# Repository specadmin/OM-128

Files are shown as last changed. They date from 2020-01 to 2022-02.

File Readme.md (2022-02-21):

# ATmega1284p Development Board #

ATmega1284p provides maximum AVR capabilities in small QFN44 package only 7х7 mm size. This controller is much better than other Atmel AVR devices (ATmega128, ATmega328, ATmega32 etc).

## Board description ##

* Programm flash size: 128 кБ
* RAM size: 16 кБ
* EEPROM size: 4кБ
* CPU clock frequency: up to 20 MHz.
* Power supply voltage: 4...6 V
* Power supply polarity protection
* Power supply filter
* 24 I/O ports
* 6 LEDs (1 power + 5 configurable)
* Reset button
* Pads for ADC reference resistors
* SPI interface
* Dimensions: 36 х 20 х 4 mm

This repository contains
* OM-128 development board schematics;
* OM-128 PCB design in Gerber format;
* a default firmware for OM-128 development board.

## PCB ##

Front view
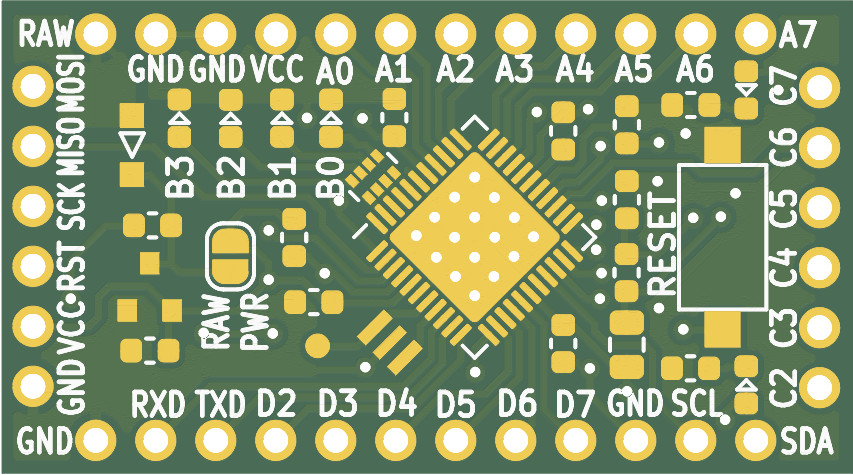
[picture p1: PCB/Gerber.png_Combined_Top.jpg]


Rear view
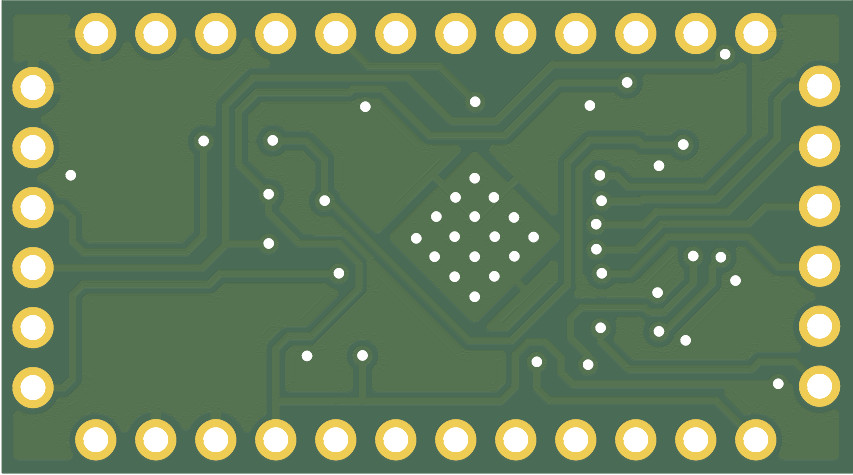
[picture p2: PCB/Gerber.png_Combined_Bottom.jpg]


## Available for purchasing ##

https://www.avito.ru/krasnodar/tovary_dlya_kompyutera/otladochnyy_modul_avr_atmega1284p_1904795755

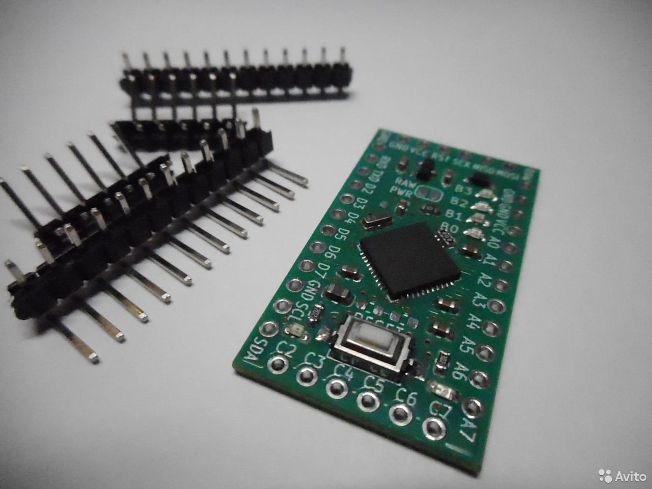
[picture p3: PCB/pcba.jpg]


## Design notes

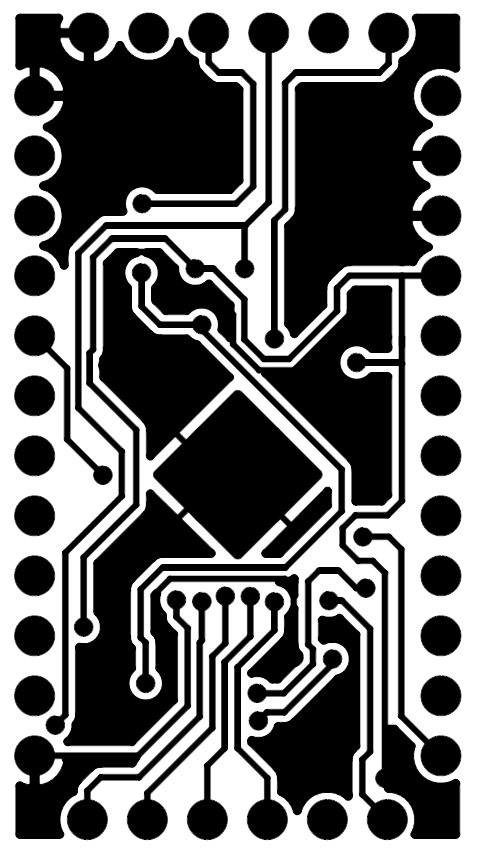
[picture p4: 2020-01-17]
PCB/Gerber_Layer_Copper_Bottom.png

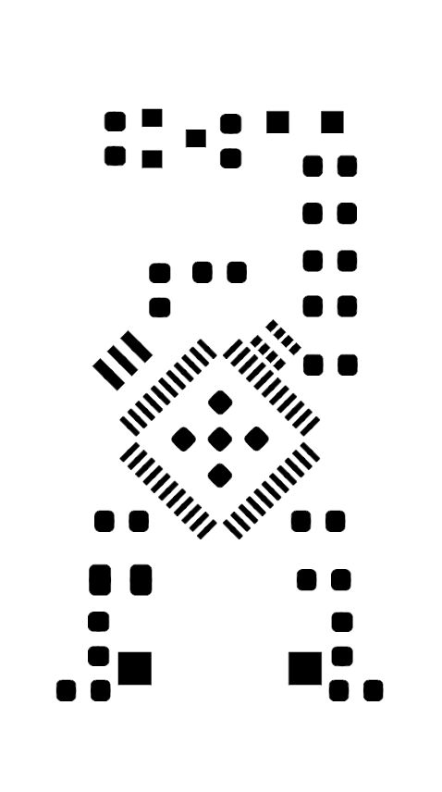
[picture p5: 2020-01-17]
PCB/Gerber_Layer_Paste_Top.png

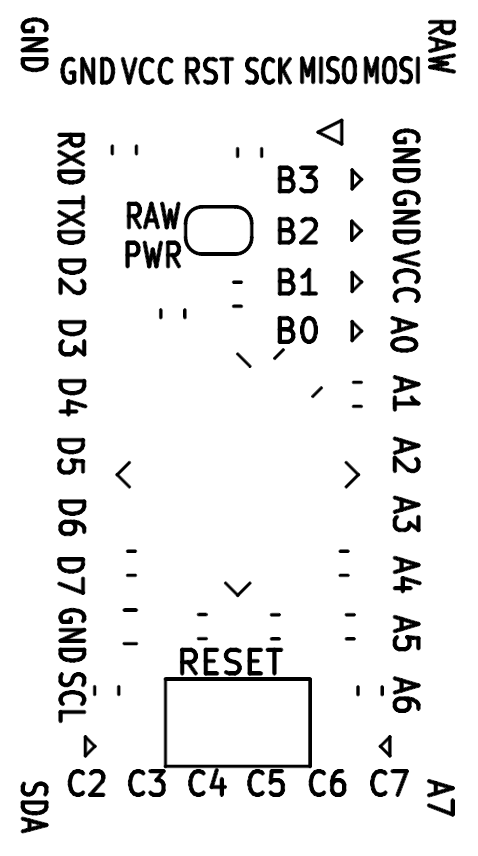
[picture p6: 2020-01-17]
PCB/Gerber_Layer_Silk_Top.png

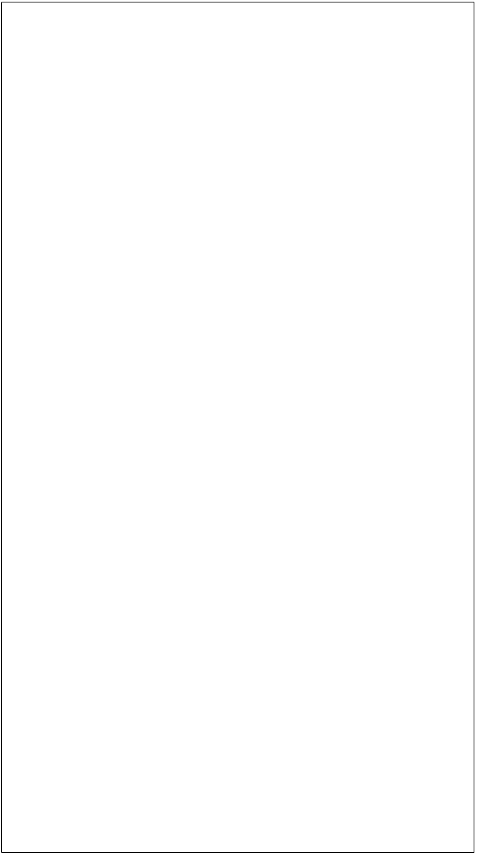
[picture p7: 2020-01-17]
PCB/Gerber_Layer_Outline_Both.png

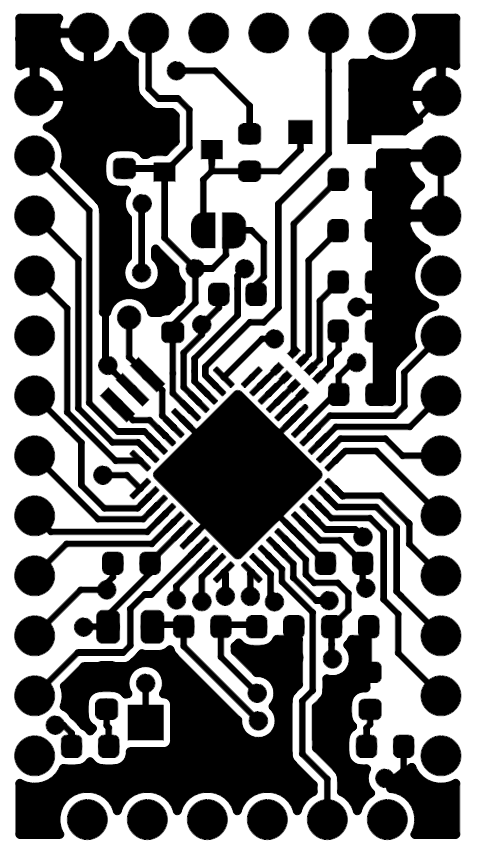
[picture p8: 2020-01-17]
PCB/Gerber_Layer_Copper_Top.png

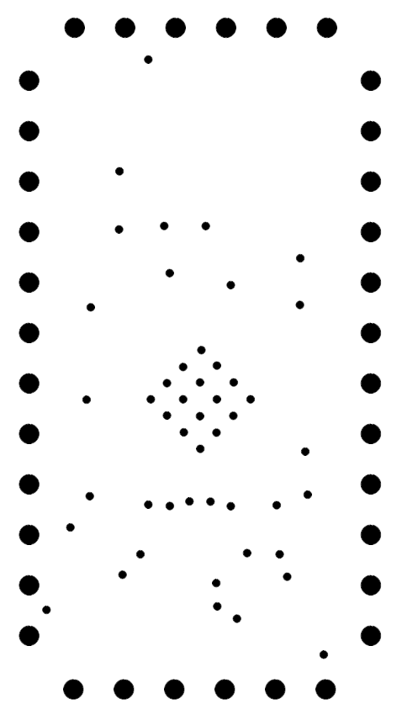
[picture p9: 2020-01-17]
PCB/Gerber_Layer_Drill_Both.png

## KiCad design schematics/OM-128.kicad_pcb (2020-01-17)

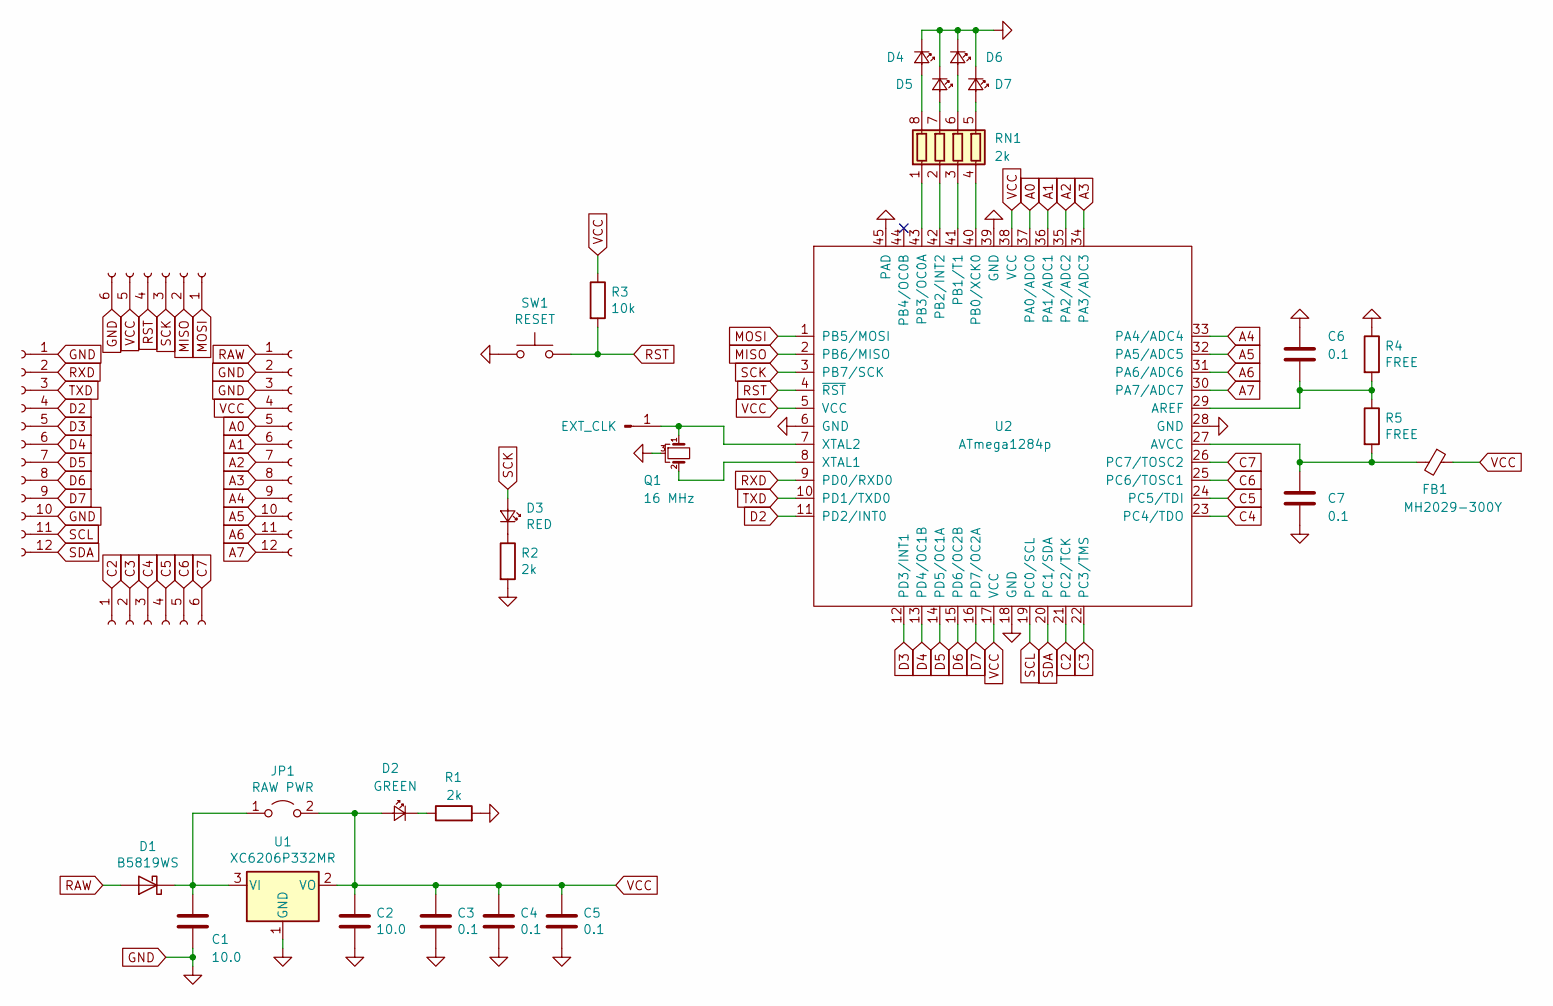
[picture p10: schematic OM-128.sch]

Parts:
C1, C2: 10.0; C_0603_1608Metric
C3, C4, C5, C6, C7: 0.1; C_0603_1608Metric
D1: B5819WS; D_SOD-323_HandSoldering
D2: GREEN; LED_0603_1608Metric
D3: RED; LED_0603_1608Metric
D4: B3; LED_0603_1608Metric
D5: B2; LED_0603_1608Metric
D6: B1; LED_0603_1608Metric
D7: B0; LED_0603_1608Metric
FB1: MH2029-300Y; L_0805_2012Metric
J1: LEFT; PinHeader_1x12_P2.54mm_Vertical
J2: TOP; PinHeader_1x06_P2.54mm_Vertical
J3: BOTTOM; PinHeader_1x06_P2.54mm_Vertical
J4: RIGHT; PinHeader_1x12_P2.54mm_Vertical
J5: EXT_CLK; TestPoint_Pad_1.0x1.0mm
JP1: RAW PWR; SolderJumper-2_P1.3mm_Open_RoundedPad1.0x1.5mm
Q1: 16 MHz; Murata_CSTCExxxxV_3213_crystal
R1, R2: 2k; R_0603_1608Metric
R3: 10k; R_0603_1608Metric
R4, R5: FREE; R_0603_1608Metric
RN1: 2k; R_Array_Concave_4x0402
SW1: RESET; SW_SPST_CK_RS282G05A3
U1: XC6206P332MR; SOT-23
U2: ATmega1284p; QFN-44-1EP_7x7mm_P0.5mm_EP5.2x5.2mm_ThermalVias

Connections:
A0: J4.5, U2.37 (PA0/ADC0)
A1: J4.6, U2.36 (PA1/ADC1)
A2: J4.7, U2.35 (PA2/ADC2)
A3: J4.8, U2.34 (PA3/ADC3)
A4: J4.9, U2.33 (PA4/ADC4)
A5: J4.10, U2.32 (PA5/ADC5)
A6: J4.11, U2.31 (PA6/ADC6)
A7: J4.12, U2.30 (PA7/ADC7)
C2: J3.1, U2.21 (PC2/TCK)
C3: J3.2, U2.22 (PC3/TMS)
C4: J3.3, U2.23 (PC4/TDO)
C5: J3.4, U2.24 (PC5/TDI)
C6: J3.5, U2.25 (PC6/TOSC1)
C7: J3.6, U2.26 (PC7/TOSC2)
D2: J1.4, U2.11 (PD2/INT0)
D3: J1.5, U2.12 (PD3/INT1)
D4: J1.6, U2.13 (PD4/OC1B)
D5: J1.7, U2.14 (PD5/OC1A)
D6: J1.8, U2.15 (PD6/OC2B)
D7: J1.9, U2.16 (PD7/OC2A)
GND: C1.2, C2.2, C3.2, C4.2, C5.2, C6.2, C7.1, D4.1 (K), D5.1 (K), D6.1 (K), D7.1 (K), J1.1, J1.10, J2.6, J4.2, J4.3, Q1.3, R1.2, R2.2, R4.1, SW1.1, U1.1 (GND), U2.6 (GND), U2.18 (GND), U2.28 (GND), U2.39 (GND), U2.45 (PAD)
MISO: J2.2, U2.2 (PB6/MISO)
MOSI: J2.1, U2.1 (PB5/MOSI)
unnamed: C1.1, D1.1 (K), JP1.1 (A), U1.3 (VI)
unnamed: C6.1, R4.2, R5.1, U2.29 (AREF)
unnamed: C7.2, FB1.2, R5.2, U2.27 (AVCC)
unnamed: D2.1 (K), R1.1
unnamed: D3.1 (K), R2.1
unnamed: D4.2 (A), RN1.8 (R1.2)
unnamed: D5.2 (A), RN1.7 (R2.2)
unnamed: D6.2 (A), RN1.6 (R3.2)
unnamed: D7.2 (A), RN1.5 (R4.2)
unnamed: J5.1, Q1.1, U2.7 (XTAL2)
unnamed: Q1.2, U2.8 (XTAL1)
unnamed: RN1.1 (R1.1), U2.43 (PB3/OC0A)
unnamed: RN1.2 (R2.1), U2.42 (PB2/INT2)
unnamed: RN1.3 (R3.1), U2.41 (PB1/T1)
unnamed: RN1.4 (R4.1), U2.40 (PB0/XCK0)
RAW: D1.2 (A), J4.1
RST: J2.4, R3.2, SW1.2, U2.4 (~RST)
RXD: J1.2, U2.9 (PD0/RXD0)
SCK: D3.2 (A), J2.3, U2.3 (PB7/SCK)
SCL: J1.11, U2.19 (PC0/SCL)
SDA: J1.12, U2.20 (PC1/SDA)
TXD: J1.3, U2.10 (PD1/TXD0)
VCC: C2.1, C3.1, C4.1, C5.1, D2.2 (A), FB1.1, J2.5, J4.4, JP1.2 (B), R3.1, U1.2 (VO), U2.5 (VCC), U2.17 (VCC), U2.38 (VCC)

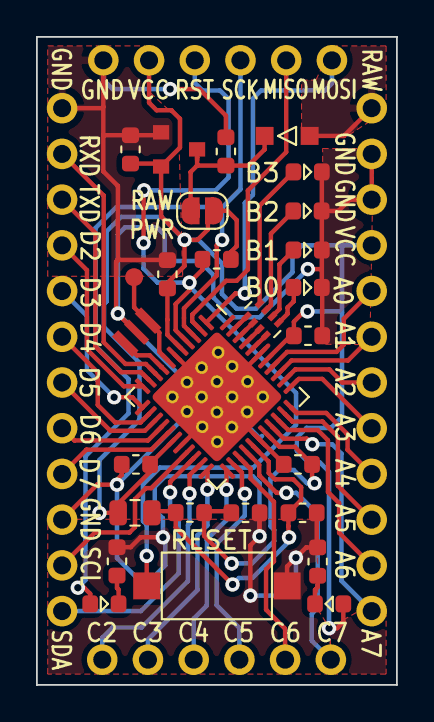
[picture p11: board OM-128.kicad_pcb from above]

Board: 2 copper layers, 20.0 x 36.0 mm, 31 parts (0 on the bottom side), 46 nets.

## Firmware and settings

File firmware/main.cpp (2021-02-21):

//-----------------------------------------------------------------------------
#include <avr/wdt.h>
#include "lib/avr-misc/avr-misc.h"
#include "lib/avr-debug/debug.h"
//-----------------------------------------------------------------------------
int main()
{
    wdt_disable();

    //DEBUG_INIT();
    set_bits(DDRB, 0, 1, 2, 3, 7);

    while(1)
    {
        //DSTR("ABCDEF");
        mdelay(500);
        set_bits(PORTB, 7);
        mdelay(500);
        set_bits(PORTB, 0);
        mdelay(500);
        set_bits(PORTB, 1);
        mdelay(500);
        set_bits(PORTB, 2);
        mdelay(500);
        set_bits(PORTB, 3);
        mdelay(500);
        clr_bits(PORTB, 0, 1, 2, 3, 7);
    }

    return 0;
}
//-----------------------------------------------------------------------------
